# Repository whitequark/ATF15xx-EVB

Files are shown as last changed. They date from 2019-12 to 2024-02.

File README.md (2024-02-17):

ATF1502-EVB
===========

*ATF1502-EVB* is a simple and low-cost evaluation board for the [Microchip ATF1502AS](https://www.microchip.com/wwwproducts/en/ATF1502AS) CPLD. It may also be used with ATF1504AS in the TQFP-44 package. It breaks out every I/O pin on a DIP-style package, exposes JTAG on a 6-pin connector, and optionally (with a solder jumper) allows two LEDs to be connected to pins 22 and 23 of the CPLD.

[PCBWay](https://www.pcbway.com/) has sponsored a prototype batch of these boards, and I'm very happy with how they turned out.  (Thanks!) See [this Twitter thread](https://twitter.com/whitequark/status/1238286231433330688) for details.

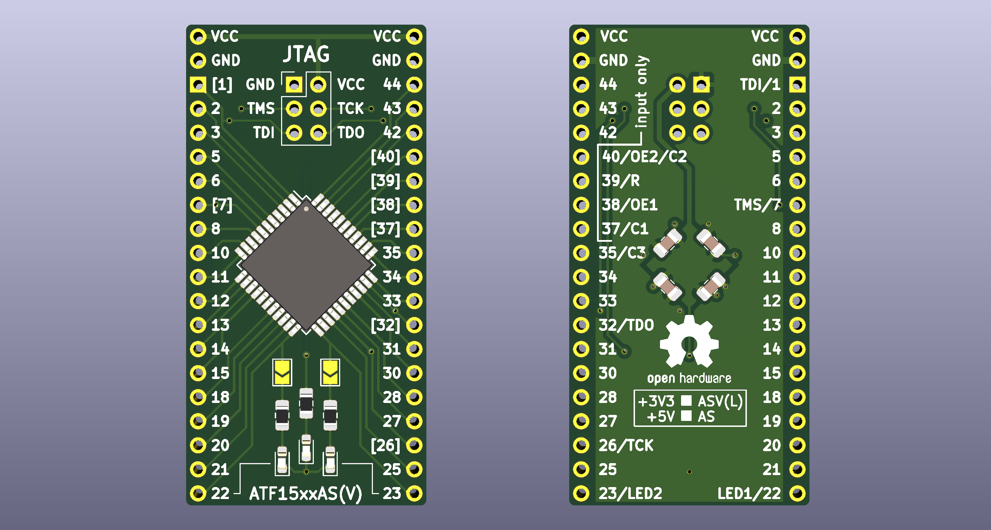
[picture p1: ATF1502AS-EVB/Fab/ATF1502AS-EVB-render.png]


See also [schematics](ATF1502AS-EVB/Fab/ATF1502AS-EVB.pdf).

ATF1502AS-EVB-PLCC44-COBBLER
============================
The *ATF1502AS-EVB-PLCC44-COBBLER* board features the same ATF1502AS CPLD, but the variant that comes in a PLCC44 package.
The style of the board is a 'cobbler', designed to be easily inserted into a breadboard.
It also features a secondary jtag port designed to be compatible with Olimex ARM-USB-TINY adapters.

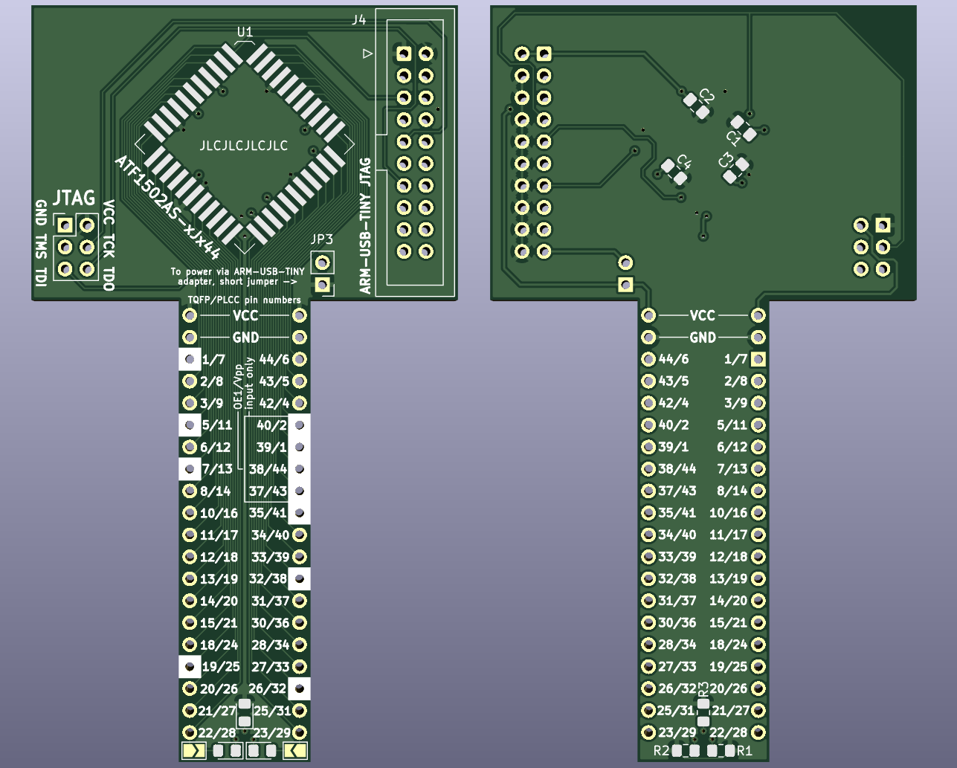
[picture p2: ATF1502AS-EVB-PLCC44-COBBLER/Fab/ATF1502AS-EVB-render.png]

See also [schematics](ATF1502AS-EVB-PLCC44-COBBLER/Fab/ATF1502AS-EVB.pdf).

ATF1508AS-EVB-PLCC84
====================
The *ATF1508AS-EVB-PLCC84* board features the bigger ATF1508AS CPLD, this board supports the variant that comes in a PLCC84 package.
It features a secondary jtag port designed to be compatible with Olimex ARM-USB-TINY adapters.

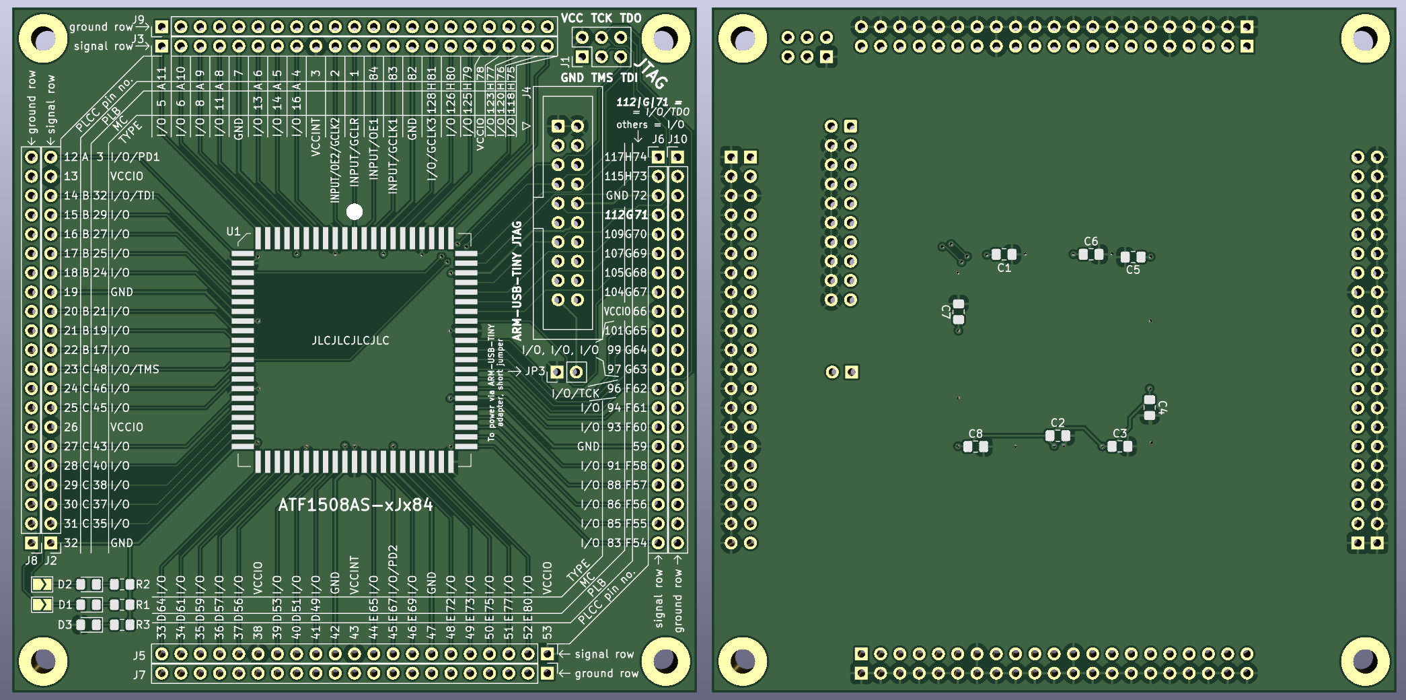
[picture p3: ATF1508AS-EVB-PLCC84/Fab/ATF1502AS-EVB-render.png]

See also [schematics](ATF1508AS-EVB-PLCC84/Fab/ATF1502AS-EVB.pdf).

ATF1502-EVB-PLCC
================
The *ATF1502-EVB-PLCC* board, is a variant for the PLCC-44 package, socketed. It routes the same signals to the headers in the same order and includes the same pin numbers on the silkscreen. These numbers reflect the TQFP-44 pin numbers, but everything is connected correctly to the PLCC-44 package, which has the same 44 signals but in a slightly different order.

License
-------

[CC0](LICENSE-CC0.txt)

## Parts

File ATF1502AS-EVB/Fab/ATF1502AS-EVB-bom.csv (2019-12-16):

RefDes | Quantity | Package | Side | Value | Manufacturer | MPN | Substitute | Comment
U1 | 1 | TQFP-44 | TOP | ATF1502AS-xAx44 | Microchip | ATF1502AS-7AX44 | NO
R2,R3,R1 | 3 | SMT_0805 | TOP | 3k3 | ANY |  | YES
C4,C3,C2,C1 | 4 | SMT_0805 | BOTTOM | 220n | ANY |  | YES
D2,D3,D1 | 3 | SMT_0603 | TOP | Green | Wurth | 150060GS75000 | YES | Cathode marked on silk

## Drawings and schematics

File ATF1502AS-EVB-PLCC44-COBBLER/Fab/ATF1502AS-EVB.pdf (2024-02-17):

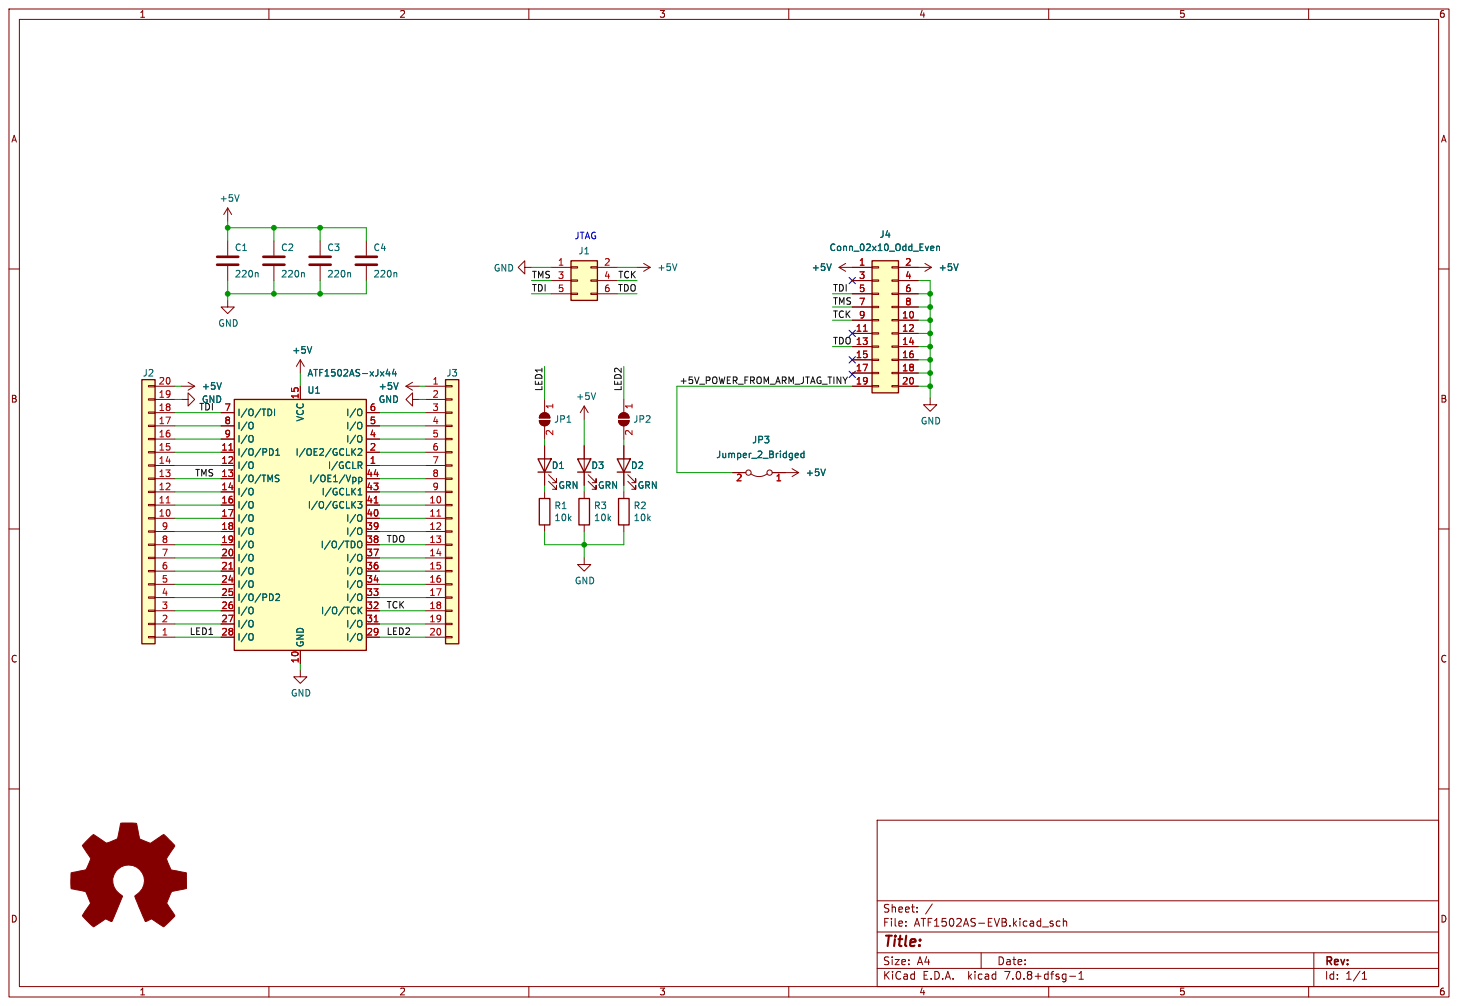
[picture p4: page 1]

Id: 1/1 Title: File: ATF1502AS-EVB.kicad_sch Sheet: /

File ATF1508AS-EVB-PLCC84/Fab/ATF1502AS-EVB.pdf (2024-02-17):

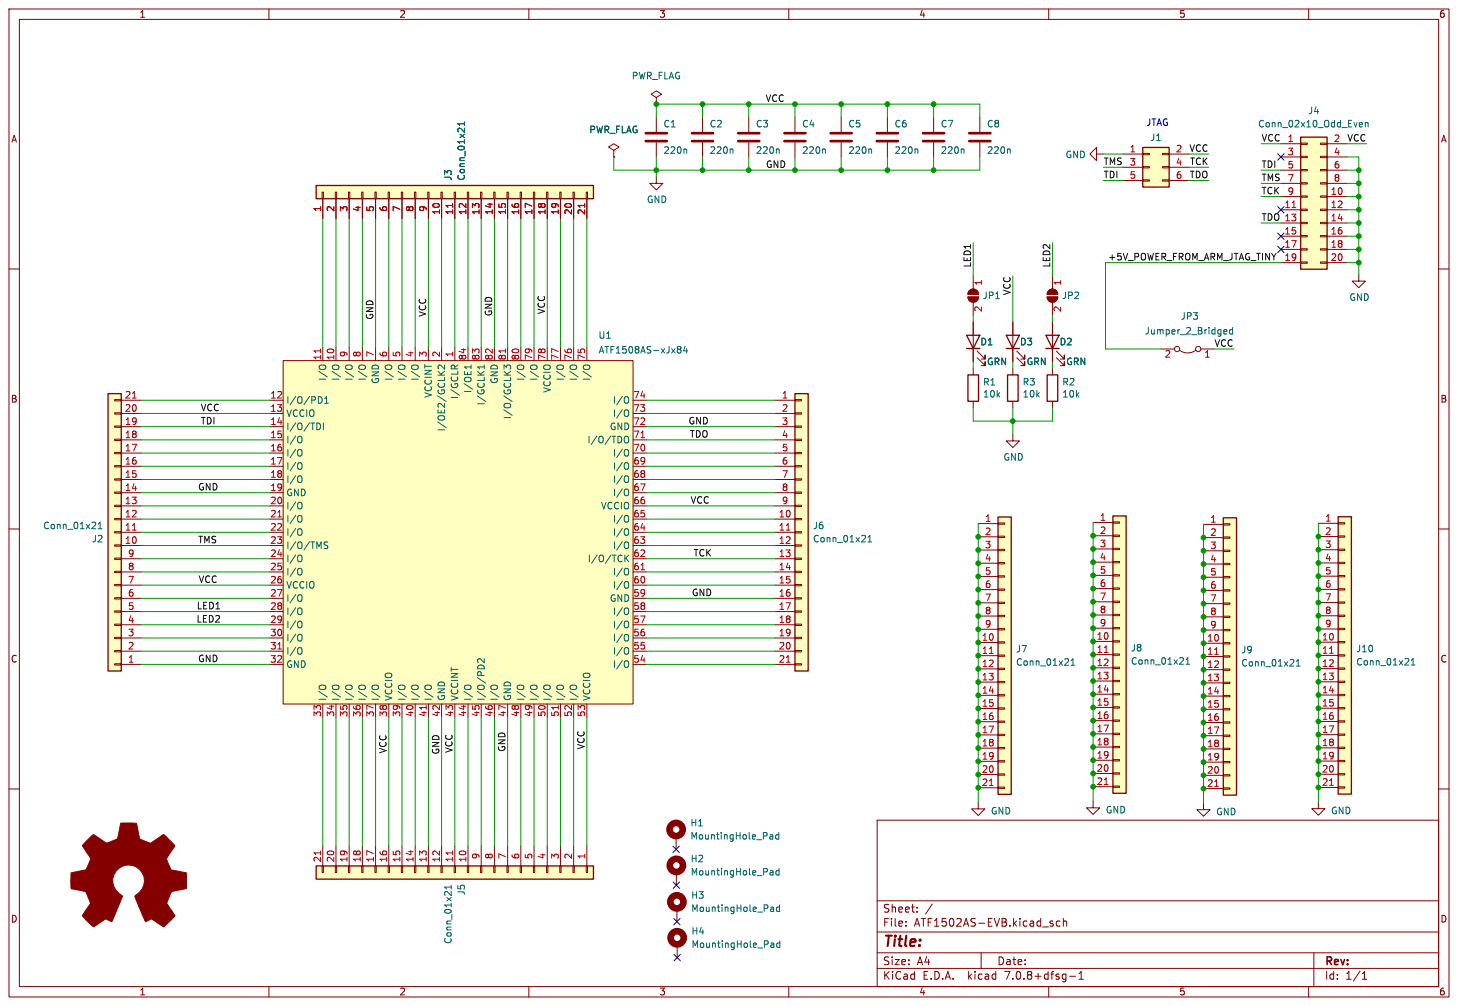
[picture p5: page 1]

Id: 1/1 Title: File: ATF1502AS-EVB.kicad_sch Sheet: /

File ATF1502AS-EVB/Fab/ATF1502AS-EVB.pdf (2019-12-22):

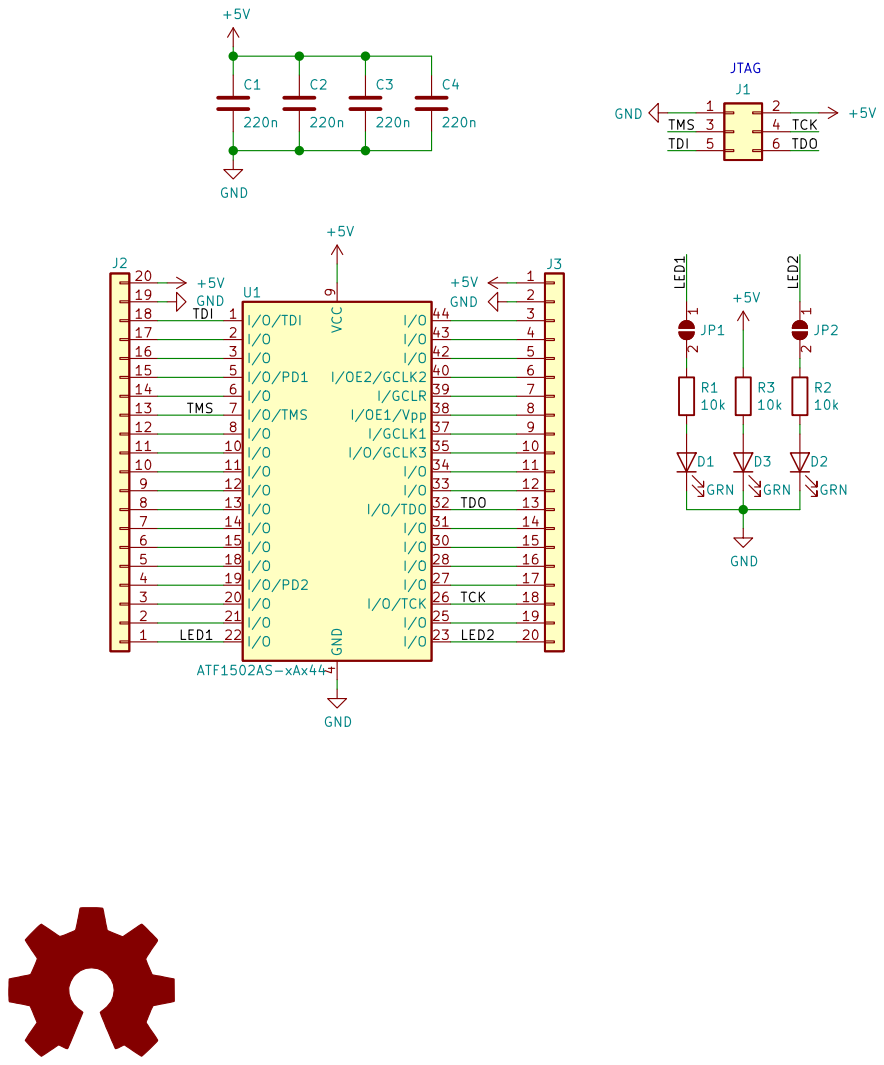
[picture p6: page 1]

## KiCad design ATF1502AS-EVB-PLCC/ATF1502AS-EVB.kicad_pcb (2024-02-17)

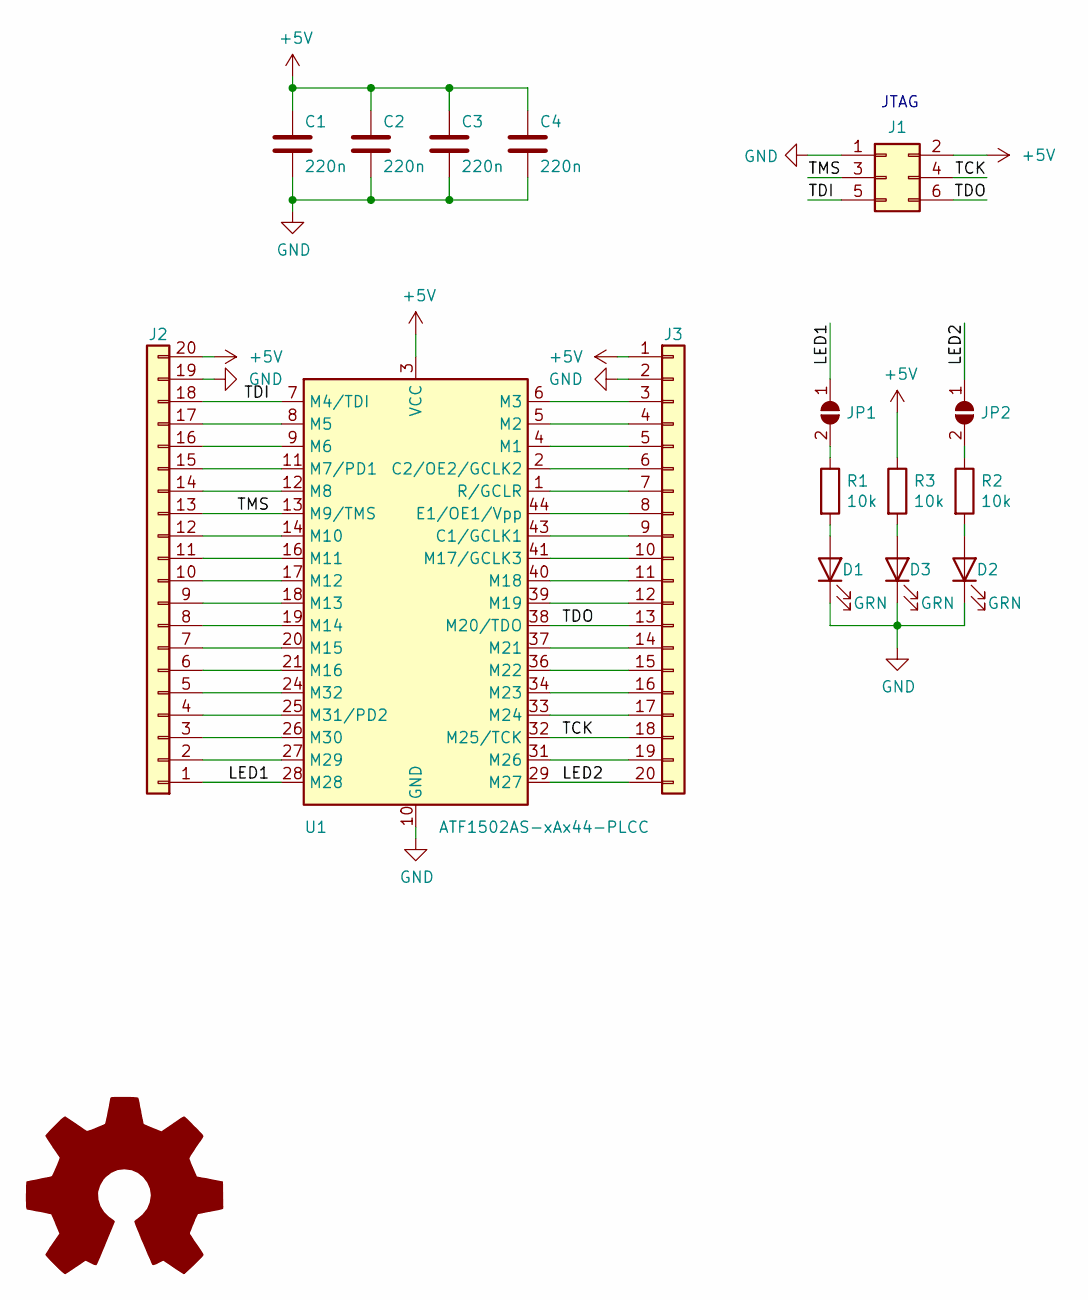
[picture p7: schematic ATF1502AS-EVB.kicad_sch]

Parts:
C1, C2, C3, C4: 220n; C_0805_2012Metric_Pad1.15x1.40mm_HandSolder
D1, D2, D3: GRN; LED_0603_1608Metric_Pad1.05x0.95mm_HandSolder; MPN 150060GS75000
J1: VERT; PinHeader_2x03_P2.54mm_Vertical
J2, J3: VERT; PinHeader_1x20_P2.54mm_Vertical_NoSilk
JP1, JP2: DNP; SolderJumper-2_P1.3mm_Open_TrianglePad1.0x1.5mm
R1, R2, R3: 10k; R_0805_2012Metric_Pad1.15x1.40mm_HandSolder
U1: ATF1502AS-xAx44-PLCC; Socket_PLCC_44; MPN ATF1502AS-7AX44

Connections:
+5V: C1.1, C2.1, C3.1, C4.1, J1.2, J2.20, J3.1, R3.1, U1.3 (VCC), U1.15 (VCC), U1.23 (VCC), U1.35 (VCC)
/LED1: J2.1, JP1.1 (A), U1.28 (M28)
/LED2: J3.20, JP2.1 (A), U1.29 (M27)
/TCK: J1.4, J3.18, U1.32 (M25/TCK)
/TDI: J1.5, J2.18, U1.7 (M4/TDI)
/TDO: J1.6, J3.13, U1.38 (M20/TDO)
/TMS: J1.3, J2.13, U1.13 (M9/TMS)
GND: C1.2, C2.2, C3.2, C4.2, D1.1 (K), D2.1 (K), D3.1 (K), J1.1, J2.19, J3.2, U1.10 (GND), U1.22 (GND), U1.30 (GND), U1.42 (GND)
unnamed: D1.2 (A), R1.2
unnamed: D2.2 (A), R2.2
unnamed: D3.2 (A), R3.2
unnamed: J2.2, U1.27 (M29)
unnamed: J2.3, U1.26 (M30)
unnamed: J2.4, U1.25 (M31/PD2)
unnamed: J2.5, U1.24 (M32)
unnamed: J2.6, U1.21 (M16)
unnamed: J2.7, U1.20 (M15)
unnamed: J2.8, U1.19 (M14)
unnamed: J2.9, U1.18 (M13)
unnamed: J2.10, U1.17 (M12)
unnamed: J2.11, U1.16 (M11)
unnamed: J2.12, U1.14 (M10)
unnamed: J2.14, U1.12 (M8)
unnamed: J2.15, U1.11 (M7/PD1)
unnamed: J2.16, U1.9 (M6)
unnamed: J2.17, U1.8 (M5)
unnamed: J3.3, U1.6 (M3)
unnamed: J3.4, U1.5 (M2)
unnamed: J3.5, U1.4 (M1)
unnamed: J3.6, U1.2 (C2/OE2/GCLK2)
unnamed: J3.7, U1.1 (R/GCLR)
unnamed: J3.8, U1.44 (E1/OE1/Vpp)
unnamed: J3.9, U1.43 (C1/GCLK1)
unnamed: J3.10, U1.41 (M17/GCLK3)
unnamed: J3.11, U1.40 (M18)
unnamed: J3.12, U1.39 (M19)
unnamed: J3.14, U1.37 (M21)
unnamed: J3.15, U1.36 (M22)
unnamed: J3.16, U1.34 (M23)
unnamed: J3.17, U1.33 (M24)
unnamed: J3.19, U1.31 (M26)
unnamed: JP1.2 (B), R1.1
unnamed: JP2.2 (B), R2.1

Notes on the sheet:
JTAG

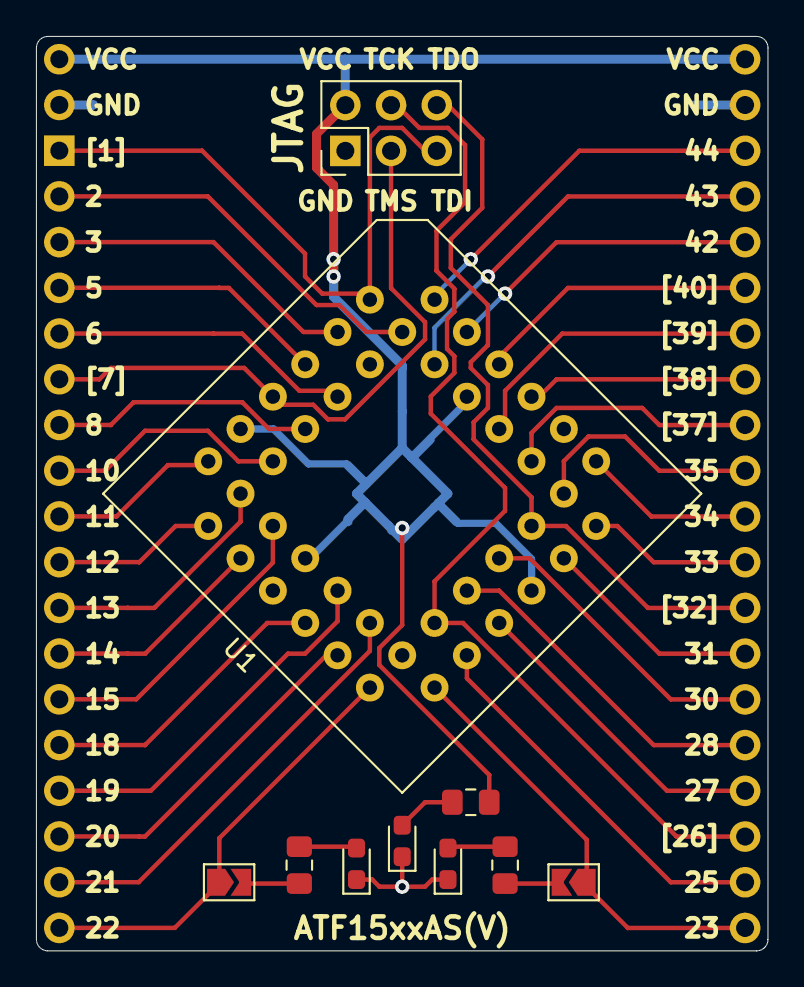
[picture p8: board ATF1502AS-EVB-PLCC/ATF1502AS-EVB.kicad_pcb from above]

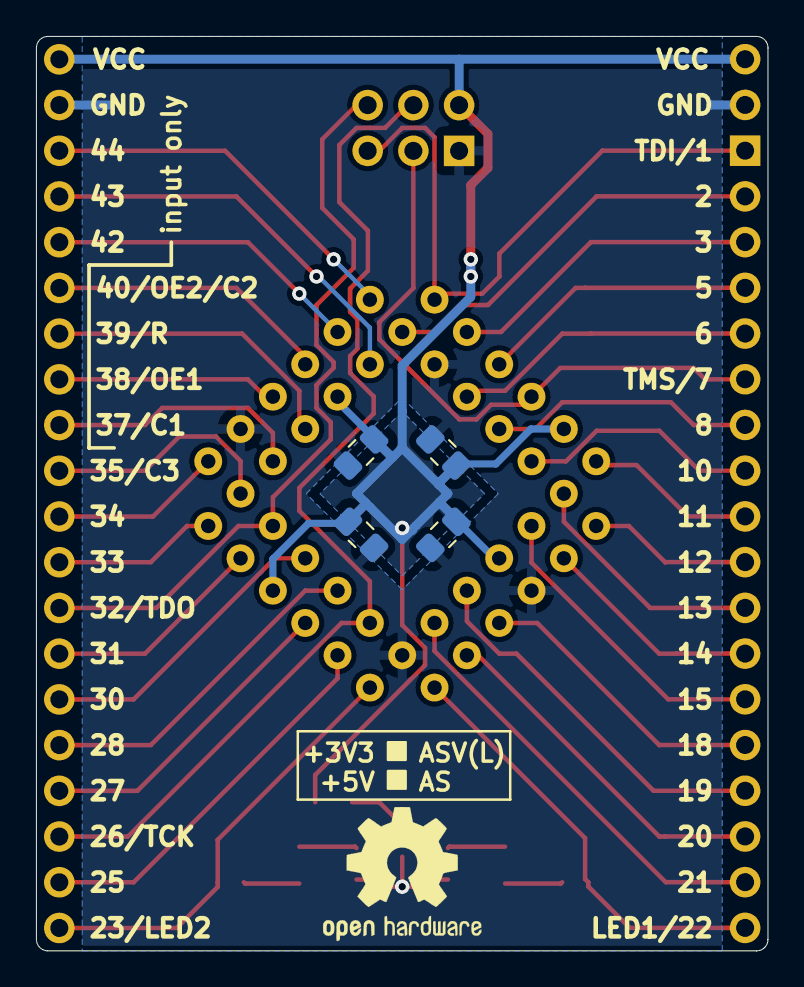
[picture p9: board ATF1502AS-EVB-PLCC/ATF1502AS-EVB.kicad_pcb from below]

Board: 2 copper layers, 40.6 x 50.8 mm, 16 parts (6 on the bottom side), 43 nets.

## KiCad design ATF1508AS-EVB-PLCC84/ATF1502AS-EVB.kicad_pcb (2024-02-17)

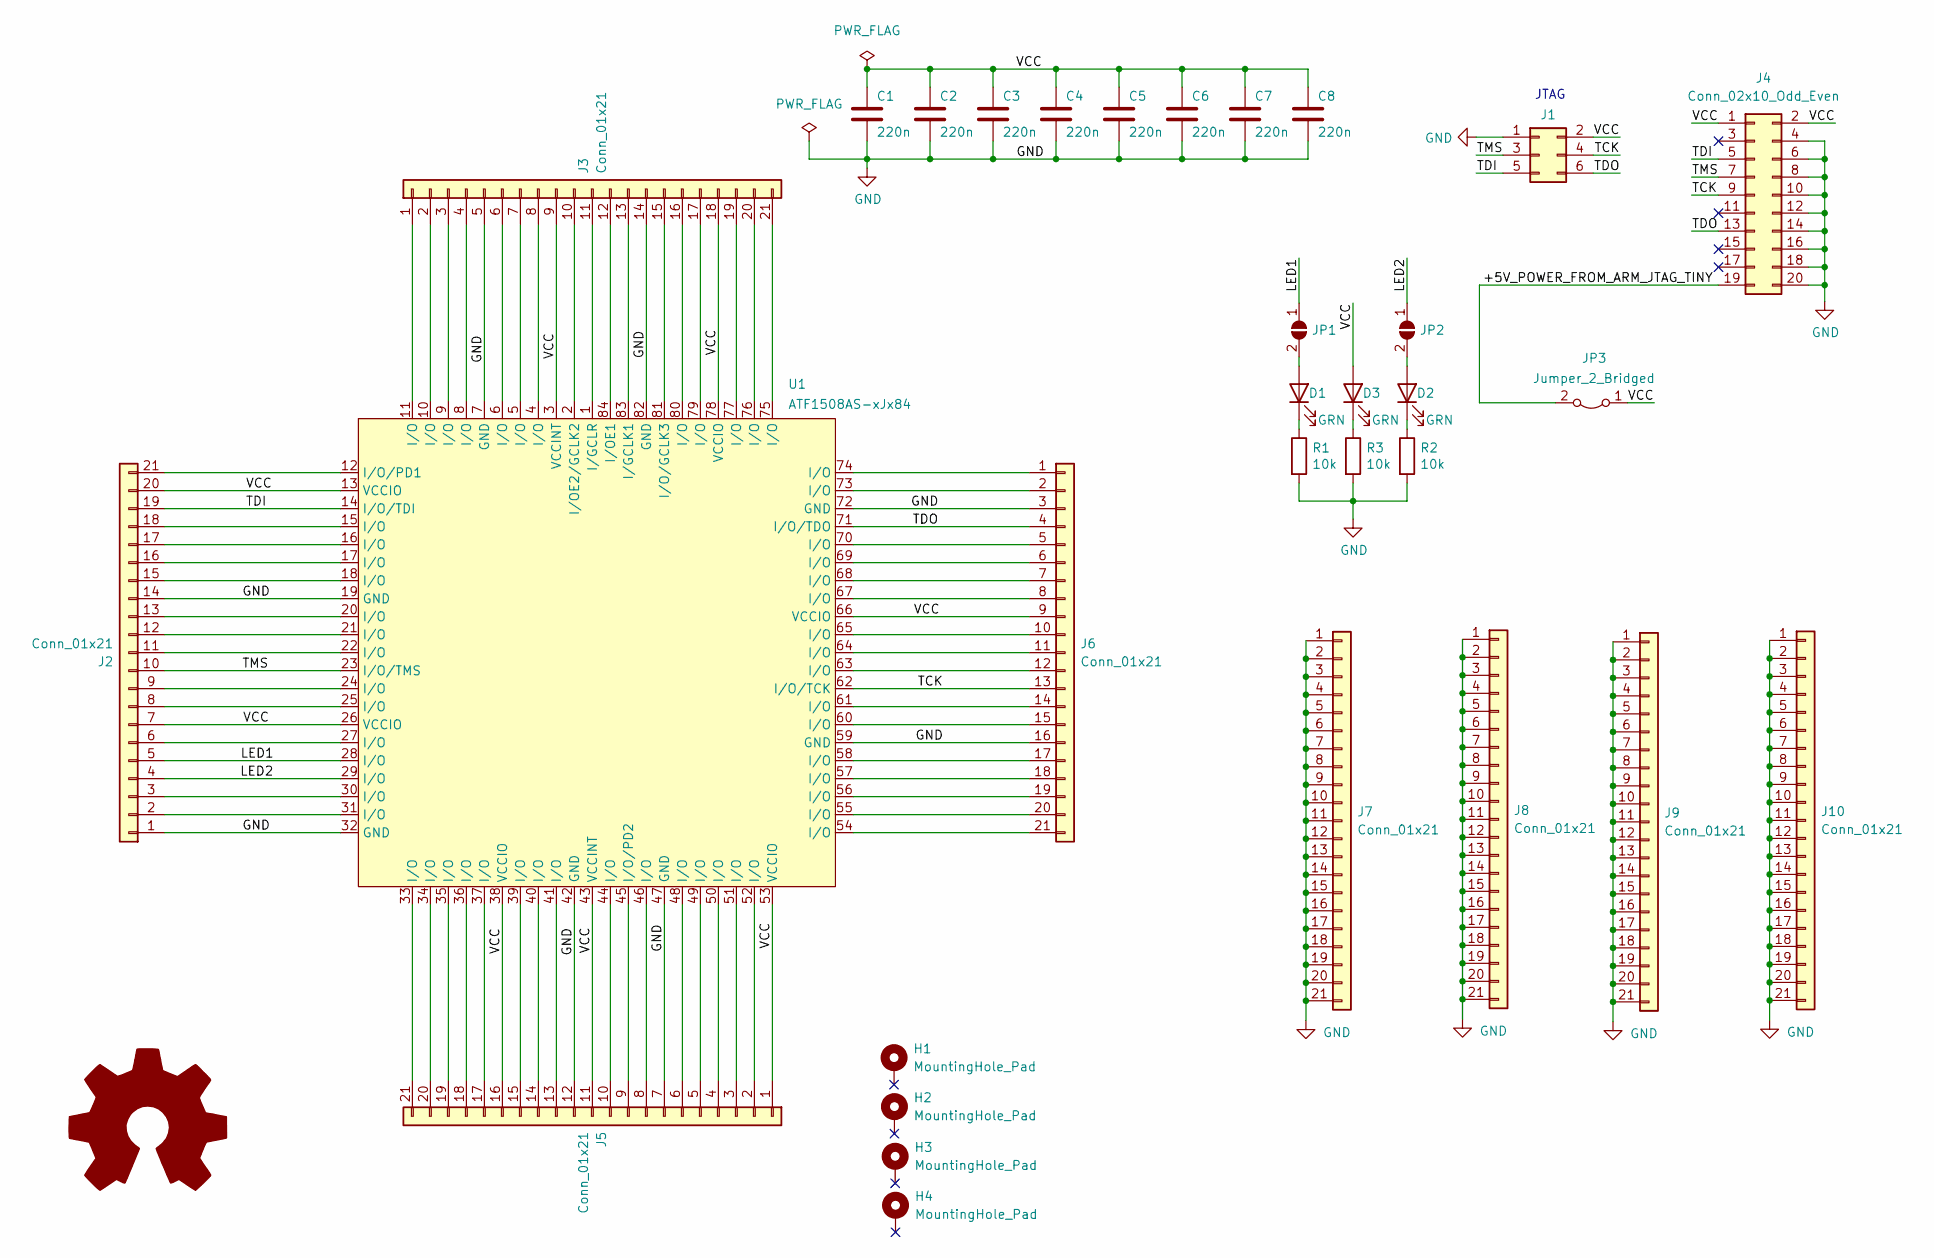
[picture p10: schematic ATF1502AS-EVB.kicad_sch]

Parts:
C1, C2, C3, C4, C5, C6, C7, C8: 220n; C_0805_2012Metric_Pad1.18x1.45mm_HandSolder
D1, D2, D3: GRN; LED_0805_2012Metric_Pad1.15x1.40mm_HandSolder; MPN 150060GS75000
H1, H2, H3, H4: MountingHole_Pad; MountingHole_3.2mm_M3_Pad
J1: VERT; PinHeader_2x03_P2.54mm_Vertical
J2, J3, J5, J6, J7, J8, J9, J10: Conn_01x21; PinHeader_1x21_P2.54mm_Vertical
J4: Conn_02x10_Odd_Even; IDC-Header_2x10_P2.54mm_Vertical
JP1, JP2: DNP; SolderJumper-2_P1.3mm_Open_TrianglePad1.0x1.5mm
JP3: Jumper_2_Bridged; PinHeader_1x02_P2.54mm_Vertical
R1, R2, R3: 10k; R_0805_2012Metric_Pad1.15x1.40mm_HandSolder
U1: ATF1508AS-xJx84; PLCC-84-handsold

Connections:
/+5V_POWER_FROM_ARM_JTAG_TINY: J4.19, JP3.2 (B)
/LED1: J2.5, JP1.1 (A), U1.28 (I/O)
/LED2: J2.4, JP2.1 (A), U1.29 (I/O)
/TCK: J1.4, J4.9, J6.13, U1.62 (I/O/TCK)
/TDI: J1.5, J2.19, J4.5, U1.14 (I/O/TDI)
/TDO: J1.6, J4.13, J6.4, U1.71 (I/O/TDO)
/TMS: J1.3, J2.10, J4.7, U1.23 (I/O/TMS)
/VCC: C1.1, C2.1, C3.1, C4.1, C5.1, C6.1, C7.1, C8.1, D3.2 (A), J1.2, J2.7, J2.20, J3.9, J3.18, J4.1, J4.2, J5.1, J5.11, J5.16, J6.9, JP3.1 (A), U1.3 (VCCINT), U1.13 (VCCIO), U1.26 (VCCIO), U1.38 (VCCIO), U1.43 (VCCINT), U1.53 (VCCIO), U1.66 (VCCIO), U1.78 (VCCIO)
GND: C1.2, C2.2, C3.2, C4.2, C5.2, C6.2, C7.2, C8.2, J1.1, J2.1, J2.14, J3.5, J3.14, J4.4, J4.6, J4.8, J4.10, J4.12, J4.14, J4.16, J4.18, J4.20, J5.7, J5.12, J6.3, J6.16, J7.1, J7.2, J7.3, J7.4, J7.5, J7.6, J7.7, J7.8, J7.9, J7.10, J7.11, J7.12, J7.13, J7.14, J7.15, J7.16, J7.17, J7.18, J7.19, J7.20, J7.21, J8.1, J8.2, J8.3, J8.4, J8.5, J8.6, J8.7, J8.8, J8.9, J8.10, J8.11, J8.12, J8.13, J8.14, J8.15, J8.16, J8.17, J8.18, J8.19, J8.20, J8.21, J9.1, J9.2, J9.3, J9.4, J9.5, J9.6, J9.7, J9.8, J9.9, J9.10, J9.11, J9.12, J9.13, J9.14, J9.15, J9.16, J9.17, J9.18, J9.19, J9.20, J9.21, J10.1, J10.2, J10.3, J10.4, J10.5, J10.6, J10.7, J10.8, J10.9, J10.10, J10.11, J10.12, J10.13, J10.14, J10.15, J10.16, J10.17, J10.18, J10.19, J10.20, J10.21, R1.2, R2.2, R3.2, U1.7 (GND), U1.19 (GND), U1.32 (GND), U1.42 (GND), U1.47 (GND), U1.59 (GND), U1.72 (GND), U1.82 (GND)
unnamed: D1.1 (K), R1.1
unnamed: D1.2 (A), JP1.2 (B)
unnamed: D2.1 (K), R2.1
unnamed: D2.2 (A), JP2.2 (B)
unnamed: D3.1 (K), R3.1
unnamed: J2.2, U1.31 (I/O)
unnamed: J2.3, U1.30 (I/O)
unnamed: J2.6, U1.27 (I/O)
unnamed: J2.8, U1.25 (I/O)
unnamed: J2.9, U1.24 (I/O)
unnamed: J2.11, U1.22 (I/O)
unnamed: J2.12, U1.21 (I/O)
unnamed: J2.13, U1.20 (I/O)
unnamed: J2.15, U1.18 (I/O)
unnamed: J2.16, U1.17 (I/O)
unnamed: J2.17, U1.16 (I/O)
unnamed: J2.18, U1.15 (I/O)
unnamed: J2.21, U1.12 (I/O/PD1)
unnamed: J3.1, U1.11 (I/O)
unnamed: J3.2, U1.10 (I/O)
unnamed: J3.3, U1.9 (I/O)
unnamed: J3.4, U1.8 (I/O)
unnamed: J3.6, U1.6 (I/O)
unnamed: J3.7, U1.5 (I/O)
unnamed: J3.8, U1.4 (I/O)
unnamed: J3.10, U1.2 (I/OE2/GCLK2)
unnamed: J3.11, U1.1 (I/GCLR)
unnamed: J3.12, U1.84 (I/OE1)
unnamed: J3.13, U1.83 (I/GCLK1)
unnamed: J3.15, U1.81 (I/O/GCLK3)
unnamed: J3.16, U1.80 (I/O)
unnamed: J3.17, U1.79 (I/O)
unnamed: J3.19, U1.77 (I/O)
unnamed: J3.20, U1.76 (I/O)
unnamed: J3.21, U1.75 (I/O)
unnamed: J5.2, U1.52 (I/O)
unnamed: J5.3, U1.51 (I/O)
unnamed: J5.4, U1.50 (I/O)
unnamed: J5.5, U1.49 (I/O)
unnamed: J5.6, U1.48 (I/O)
unnamed: J5.8, U1.46 (I/O)
unnamed: J5.9, U1.45 (I/O/PD2)
unnamed: J5.10, U1.44 (I/O)
unnamed: J5.13, U1.41 (I/O)
unnamed: J5.14, U1.40 (I/O)
unnamed: J5.15, U1.39 (I/O)
unnamed: J5.17, U1.37 (I/O)
unnamed: J5.18, U1.36 (I/O)
unnamed: J5.19, U1.35 (I/O)
unnamed: J5.20, U1.34 (I/O)
unnamed: J5.21, U1.33 (I/O)
unnamed: J6.1, U1.74 (I/O)
unnamed: J6.2, U1.73 (I/O)
unnamed: J6.5, U1.70 (I/O)
unnamed: J6.6, U1.69 (I/O)
unnamed: J6.7, U1.68 (I/O)
unnamed: J6.8, U1.67 (I/O)
unnamed: J6.10, U1.65 (I/O)
unnamed: J6.11, U1.64 (I/O)
unnamed: J6.12, U1.63 (I/O)
unnamed: J6.14, U1.61 (I/O)
unnamed: J6.15, U1.60 (I/O)
unnamed: J6.17, U1.58 (I/O)
unnamed: J6.18, U1.57 (I/O)
unnamed: J6.19, U1.56 (I/O)
unnamed: J6.20, U1.55 (I/O)
unnamed: J6.21, U1.54 (I/O)

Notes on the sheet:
JTAG

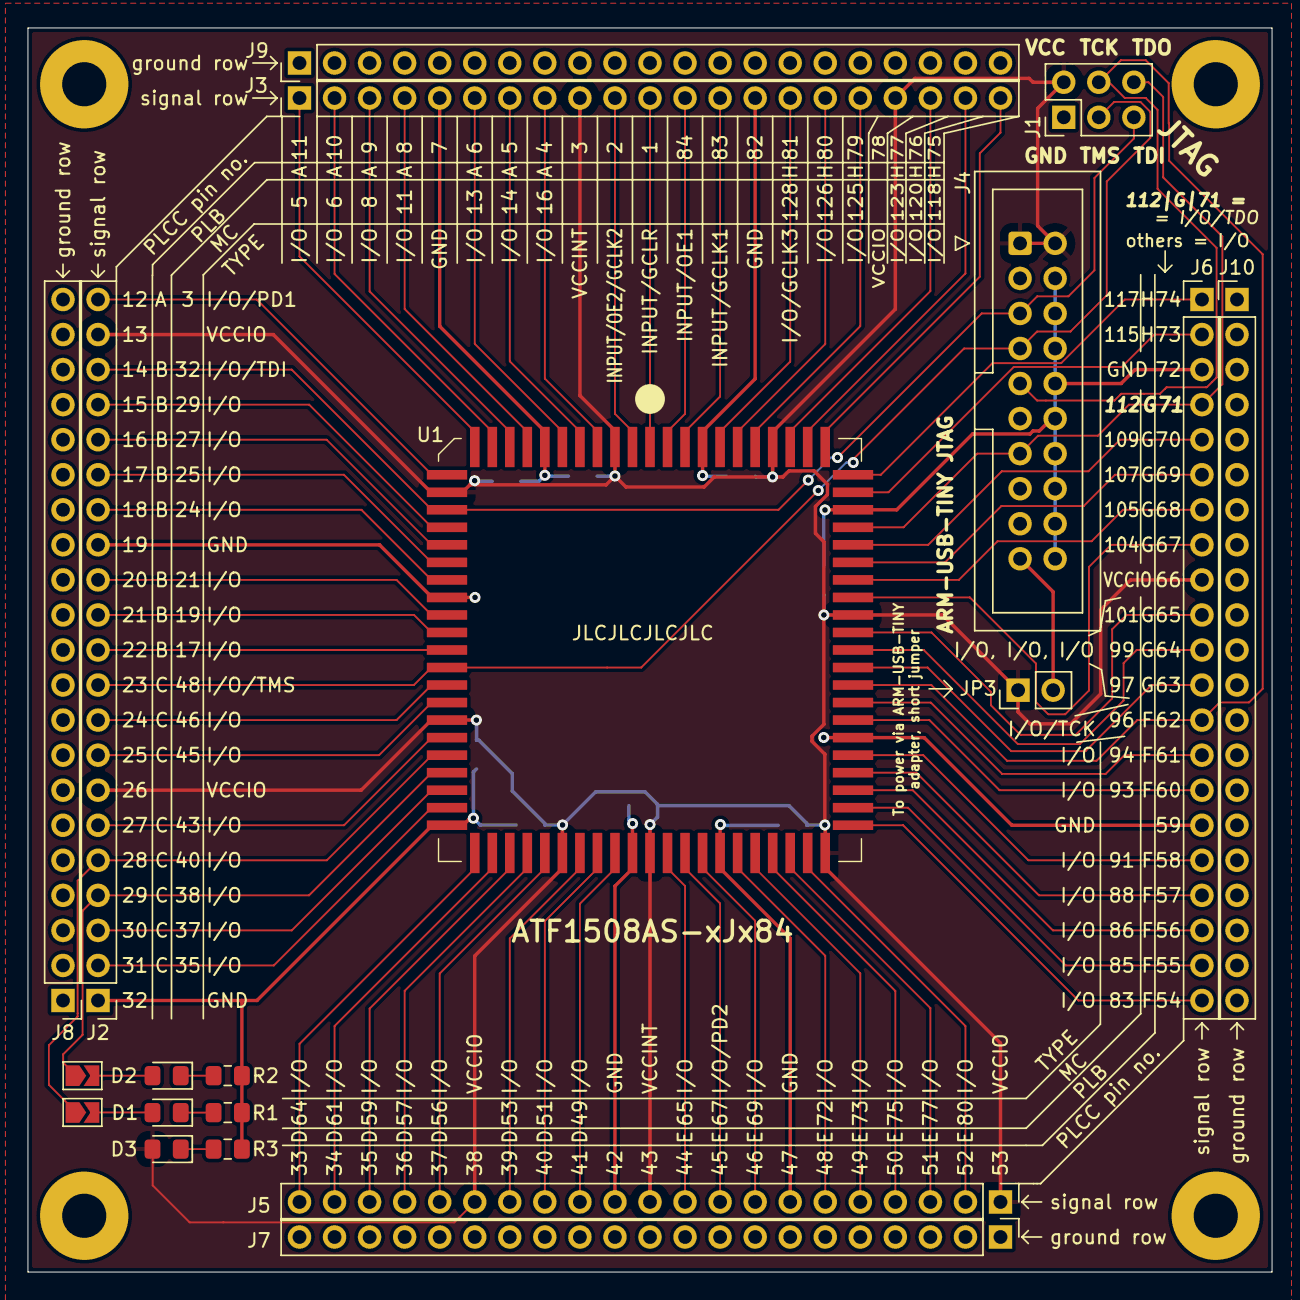
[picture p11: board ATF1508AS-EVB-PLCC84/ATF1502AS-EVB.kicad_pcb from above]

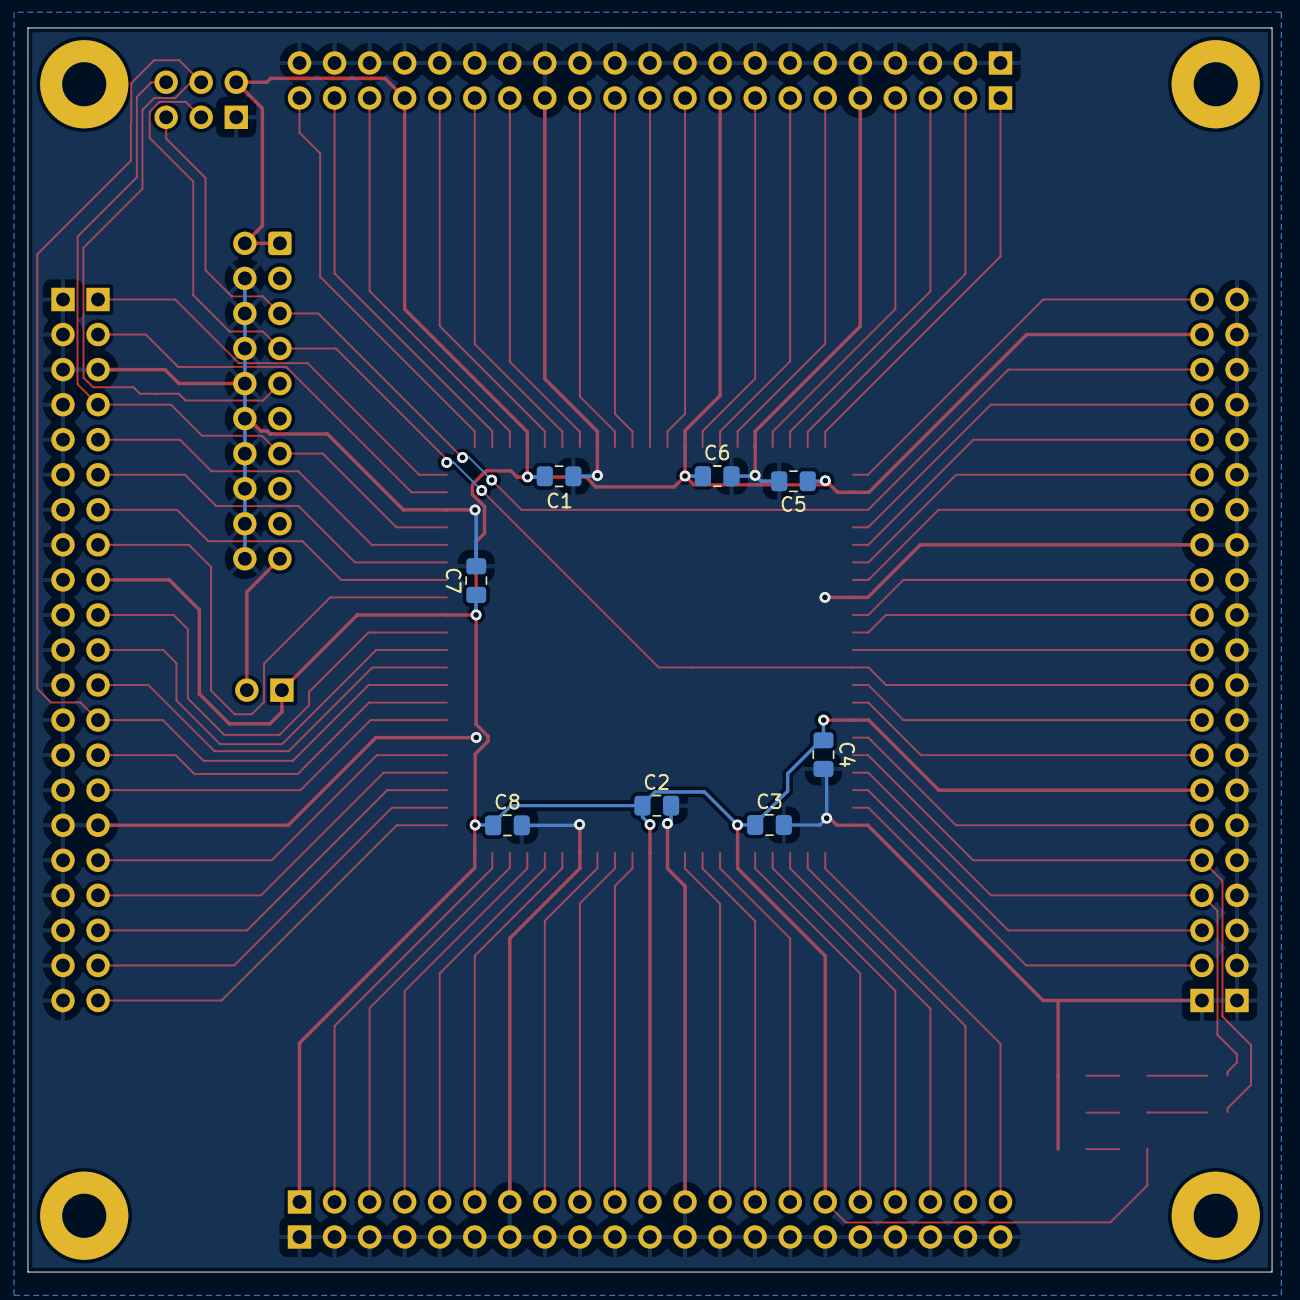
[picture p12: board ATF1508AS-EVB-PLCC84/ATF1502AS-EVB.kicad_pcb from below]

Board: 2 copper layers, 90.2 x 90.2 mm, 32 parts (8 on the bottom side), 76 nets.

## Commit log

2019-12-12 Add ATF1502AS-EVB.
    [ATF1502AS-EVB.kicad_pcb, ATF1502AS-EVB.sch]
2019-12-12 ATF1502AS-EVB: show LED<>pin correspondence on silk.
    [ATF1502AS-EVB.kicad_pcb]
2019-12-12 ATF1502AS-EVB: improve symmetry further.
    [ATF1502AS-EVB.kicad_pcb]
2019-12-15 Update for upstream changes.
    [ATF1502AS-EVB.kicad_pcb, ATF1502AS-EVB.sch]
2019-12-16 ATF1502AS-EVB: final changes for fab.
    [ATF1502AS-EVB.kicad_pcb, ATF1502AS-EVB.sch]
2019-12-16 ATF1502AS-EVB: add fab outputs.
    [ATF1502AS-EVB-B_Cu.gbr, ATF1502AS-EVB-B_Mask.gbr, ATF1502AS-EVB-B_Paste.gbr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]
2019-12-22 Add README, relicense to CC0.
    There's no meaningful difference between BSD0 and CC0, but it seems
    ambiguous to use BSD0 for PCBs when it specifically says "software".
2021-01-22 Modify silkscreen for 3v3 and 5v parts.
    [ATF1502AS-EVB-B_Cu.gbr, ATF1502AS-EVB-B_Mask.gbr, ATF1502AS-EVB-B_Paste.gbr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]
2024-02-17 Added ATF1502AS-EVB-PLCC44-COBBLER
    [ATF1502AS-EVB-B_Cu.gbr, ATF1502AS-EVB-B_Mask.gbr, ATF1502AS-EVB-B_Paste.gbr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]
2024-02-17 Added ATF1508AS-EVB-PLCC84
    [ATF1502AS-EVB-B_Cu.gbr, ATF1502AS-EVB-B_Mask.gbr, ATF1502AS-EVB-B_Paste.gbr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]
2024-02-17 ATF1502AS-EVB-PLCC: Provide a PLCC Variant EVB
    - Created a new symbol for the PLCC version which has a different pinout
    - Widened the board to allow for the larger PLCC socket.
    - The silkscreen numbers and header pin order matches that of the TQFP
    version of the board, but everything is routed to the correct TQFP pins.
    [ATF1502AS-EVB.kicad_pcb, ATF1502AS-EVB.kicad_sch]
